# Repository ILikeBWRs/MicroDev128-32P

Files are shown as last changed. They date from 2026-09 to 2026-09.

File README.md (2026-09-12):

### *Thank You to PCBWay for sponsoring this project! To see more look up the "Sponsorship Section"*

---

Main Project Page:[MicroDev128 project](https://github.com/ILikeBWRs/MicroDev128)

---

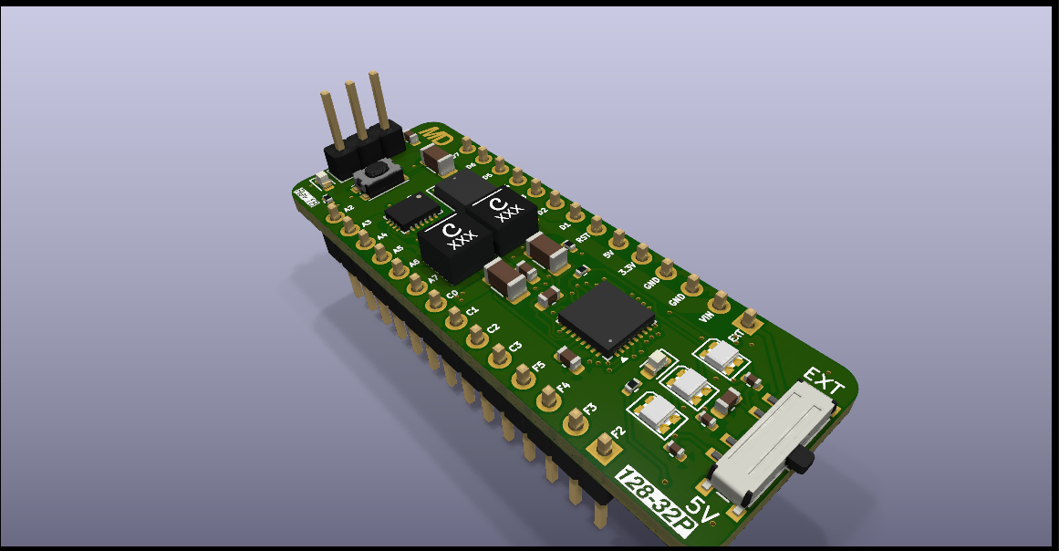
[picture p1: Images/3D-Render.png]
Project Image

# MicroDev128-32P
## A high-power development/prototyping board with MVIO. 

Based on the AVR128DB32. 

The MicroDev128-32P is open-source development board with a high-power voltage regulator with up to 2A continous, Multi-voltage IO - which allows PortC to run on a different voltage than the rest of the board - elimenating the need for voltage level shifters. The MicroDev128-32P aims to be better price to performance ratio than a tradition Arduino Nano. To view the Schematics you can go into the Kicad files folder. All files were made on KiCad 10.04 and should import without other dependencies. The 3D models are all included in the folder. 

**Key Specifications:**
- Up to 2A continuos on both power lines, 3.3v and 5v with up to 42VDC input
- Arduino Nano sized footprint, allowing it to easily be plugged into breadboards
- 128kB Flash, 16kB SRAM, and 512B EEPROM
- Has with internal clock adjustable up to 24MHz max
- Built in reverse polarity protection, fuse and overcurrent/short protection
- UPDI Header for programming 
- Onboard LED and 3 programble, seperatly adressable NeoPixels

## Documentation

For Documentation see the MicroDev128 Docs repository. This includes technical information such as regulator ripple, tests etc. 
[Link to Documents](https://github.com/ILikeBWRs/MicroDev128-Documentation)

---

## Images
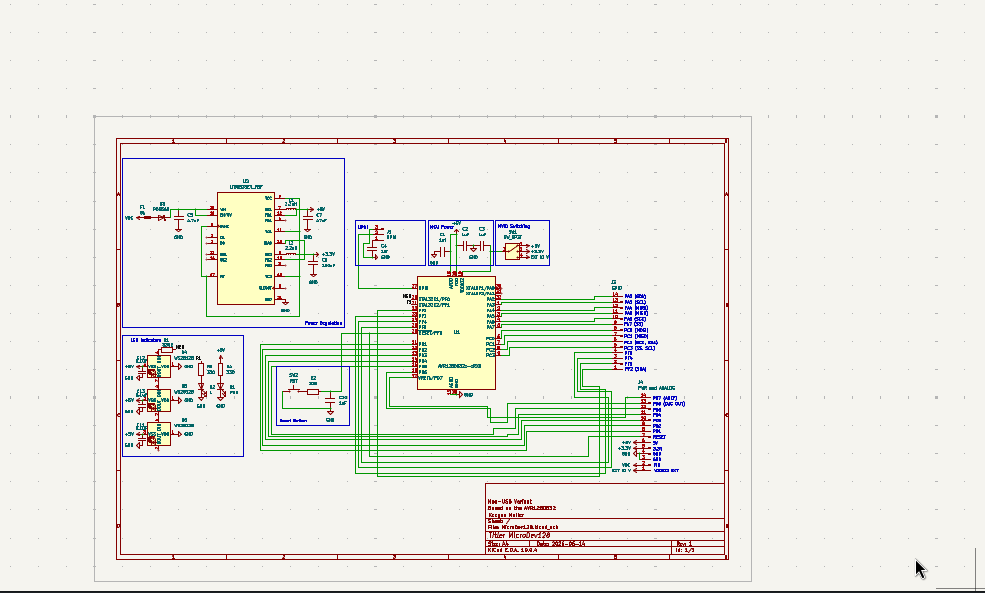
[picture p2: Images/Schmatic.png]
Schematic

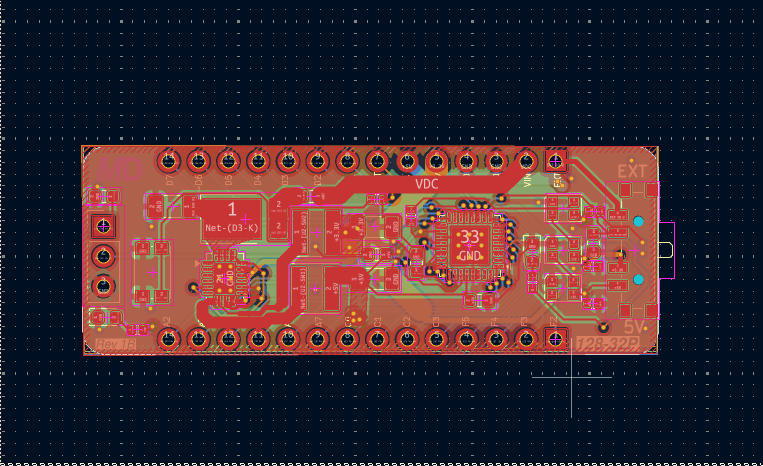
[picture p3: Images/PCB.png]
PCB Layout

3D Render

---

## Ordering

To order your own you have a few ways:

**1. Order Blank PCBs and assemble them yourself**

*You will need a hotplate for solder reflow and solder paste. May be cheaper but harder to do!*

Upload the Gebers at:
/MicroDev128-32P Production Files
   /Gebers.zip
Go to PCBWay's online ordering page and upload the gebers. Make sure it says 4-layers. Set it to ENIG, and set the solder mask to any colour you want. The rest of the default settings will be fine. Hit order or add stencil if you need one. It's that easy!

Next in the same folder find the BOM.csv and order the parts from your favorite part distributor. 
To lay out components once they turn up you can use the KiCad PCB layout. A dedicated image for this step will come later.

**2. Use PCBWay's PCBA service and get them shipped assembled**

Upload the Gebers at:

/Production Files

   /Gebers.zip
   
Go to your PCB and upload the gebers. Make sure it says 4-layers. Set it to ENIG, and set the solder mask to any colour you want. The default settings will be fine.
Then upload the BOM.csv and CPL.csv to the page. Then check if they in stock. (You may need to pre-order some parts!)
The check component orientation - it has a tendency to flip the LT8653S by 90 degrees. 
Then pay and let PCBWay's professional automated factory ship them fully assembled, right to your door!

---

## Revision Information

This repository was last updated: *2026-09-12*

This design is revision: *1B*

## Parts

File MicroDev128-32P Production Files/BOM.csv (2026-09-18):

Ref Des | Footprint | Quantity | Designation | Manufacturer | Mfg Part# | Desciption/Value | Package | Type | Notes
C1, C2, C3, C4 | C_0603_1608Metric | 4 | 1uf | Yageo | CC0603KRX5R6BB105 | 1uF 0603 X5R, ±10% | 603 | SMD | Not strict – generic options will work fine if they match the specifications.
C5 | C_1206_3216Metric | 1 | 4.7uF | Murata | GRM31CC72A475KE11K | 4.7uF 1206 ±10% X7S | 1206 | SMD
C6 | C_1206_3216Metric | 1 | 100uF | Murata | GRM31CR60J107ME39L | 100µF, 6.3V, ±20% X5R | 1206 | SMD
C7 | C_1206_3216Metric | 1 | 47uF | Murata | GRM31CR61A476ME15L | 47µF, 10V, ±20% X5R | 1206 | SMD
C10 | C_0603_1608Metric | 1 | 1uF | Yageo | CC0603KRX5R6BB105 | 1uF 0603 X5R, ±10% | 603 | SMD
C11, C12, C13 | C_0402_1005Metric | 3 | 0.1uF | Murata | GRM155R71A104KA01D | 0.1uF 402 ±10% X7R | 402 | SMD
D1 | LED_0603_1608Metric | 1 | PWR | Everlight | 19-217/R6C-AL1M2VY/3T | Standard Red SMD Led | 603 | SMD
D2 | LED_0603_1608Metric | 1 | L | Everlight | 19-217/R6C-AL1M2VY/3T | Standard Red SMD Led | 603 | SMD
D3 | D_PowerDI-5 | 1 | PDS560 | Diodes Incorporated | PDS560-13 | Schottky 60V 5A | PowerDI-5 | SMD
D4, D5, D6 | LED_WS2812B-2020_PLCC4_2.0x2.0mm | 3 | WS2812B | Worldsemi | WS2812B-2020 | RGB with IC, 5V, 2.0x2.0mm | PLCC-4 | SMD
F1 | Fuse_0603_1608Metric | 1 | 5A | Bourns | SF-0603F500-2 | 5A, 32V, Fast-Acting | 603 | SMD
J1 | PinHeader_1x03_P2.54mm_Vertical | 1 | UPDI | DNP | DNP | DNP | DNP | DNP | No Not Place
J3 | PinHeader_1x14_P2.54mm_Vertical | 1 | GPIO | DNP | DNP | DNP | DNP | DNP | No Not Place
J4 | PinHeader_1x14_P2.54mm_Vertical | 1 | PWR and ANALOG | DNP | DNP | DNP | DNP | DNP | No Not Place
L1, L2 | L_Taiyo-Yuden_NR-40xx | 2 | 2.2uH | Taiyo Yuden | NR4018T2R2M | 2.2µH, ±20%, 2.70A | 4.0x4.0mm | SMD
R1 | R_0402_1005Metric | 1 | 330R | Yageo | RC0402FR-07330RL | 330Ohm 1% 1/16W Metal film resistor | 402 | SMD
R2, R3, R4 | R_0402_1005Metric | 3 | 330R | Yageo | RC0402FR-07330RL | 330Ohm 1% 1/16W Metal film resistor | 402 | SMD
SW1 | SW_SP3T_PCM13 | 1 | SW_SP3T | C&K / Littelfuse | PCM13SMTR | Slide, SP3T, 3-Position, 0.3A 6VDC | PCM13 | SMD
SW2 | SW_Push_1P1T_NO_CK_KMR2 | 1 | RST | C&K / Littelfuse | KMR221G LFS | SPST-NO, Top Actuated, 50mA 32VDC | 4.6x2.8mm | SMD
U1 | QFN-32-1EP_5x5mm_P0.5mm_EP3.1x3.1mm | 1 | AVR128DB32x-xRXB | Microchip Technology | AVR128DB32-E/RXB | AVR Microcontroller, 128kB Flash | QFN-32 | SMD
U2 | QFN-20-1EP_3x4mm_P0.5mm_EP1.65x2.65mm | 1 | LT8653SEV_PBF | Analog Devices | LT8653SEV#PBF | Silent Switcher2 High Power Buck Reg | QFN-20 | SMD

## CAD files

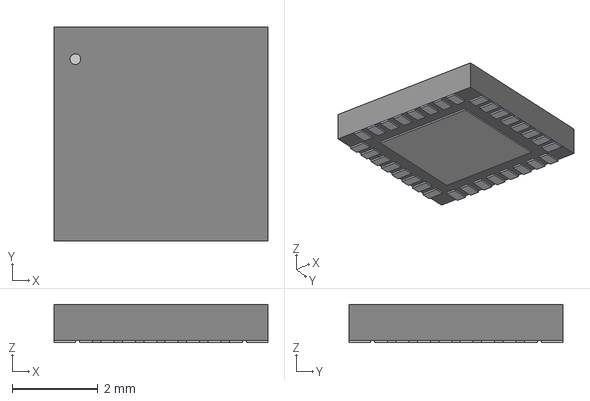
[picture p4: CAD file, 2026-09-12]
KiCad Files/3D Models/VQFN32_RXB_MCH.step
5.00 x 5.00 x 0.892 mm

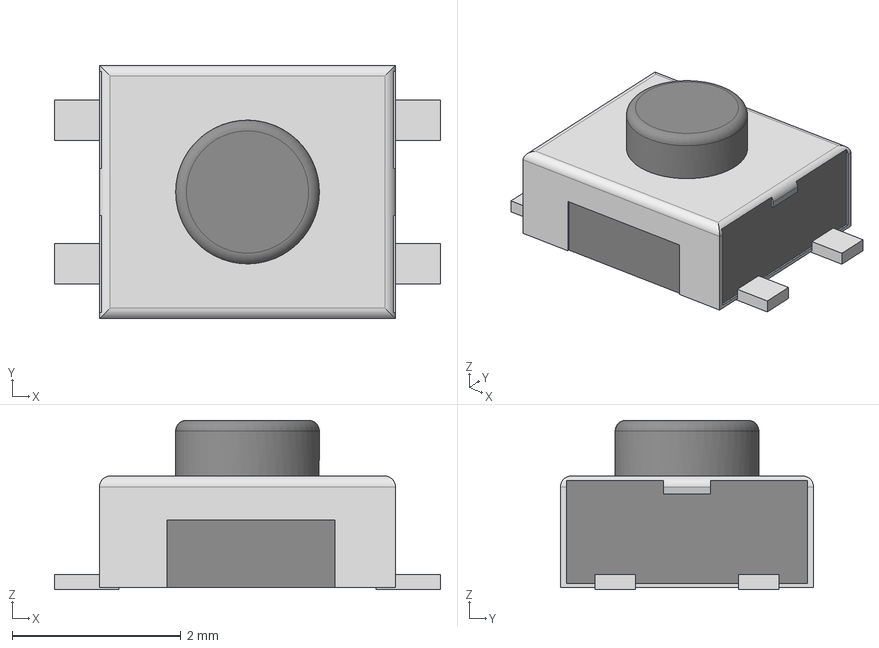
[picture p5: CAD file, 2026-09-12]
KiCad Files/3D Models/3x4x2mm.stp
4.57 x 3.00 x 2.01 mm

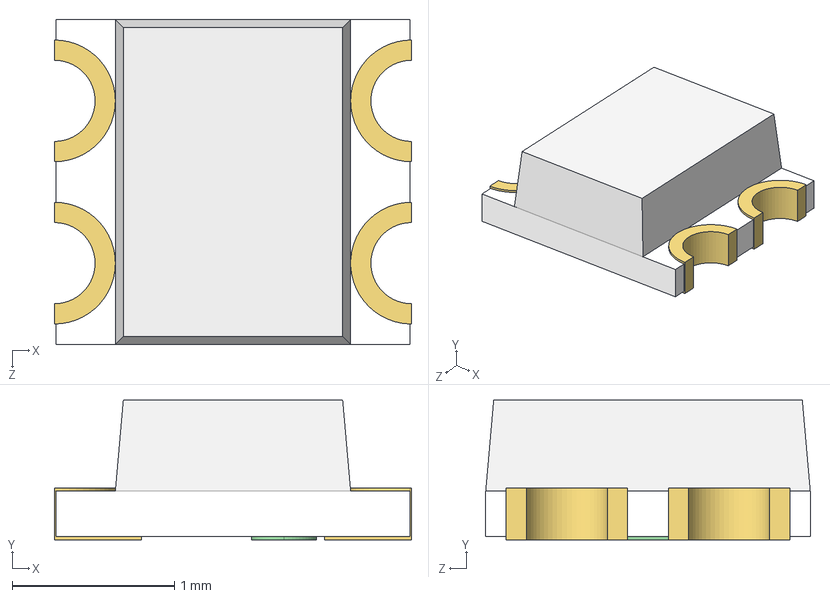
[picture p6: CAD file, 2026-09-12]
KiCad Files/3D Models/WS2812-2020.STEP
2.20 x 0.86 x 2.00 mm

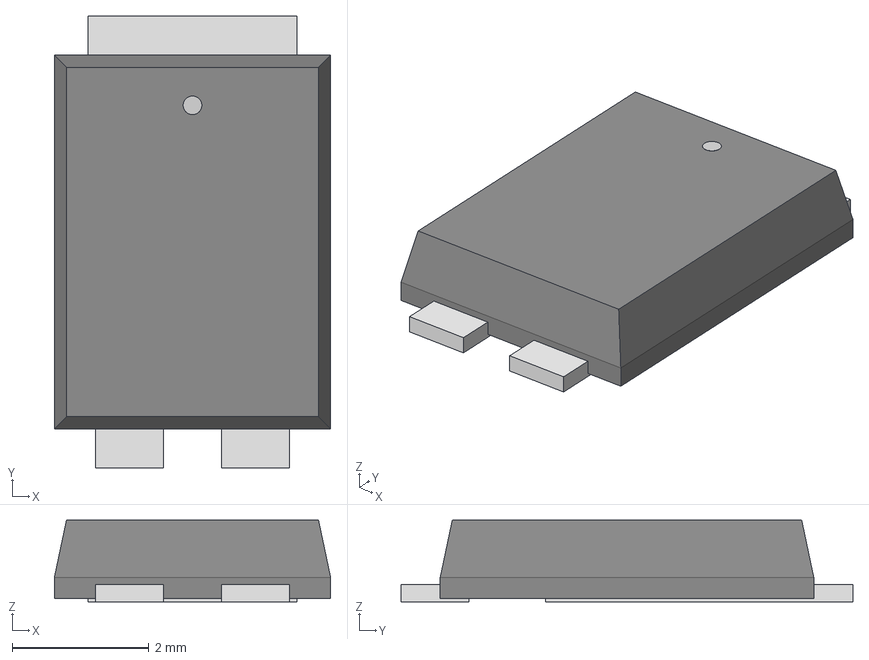
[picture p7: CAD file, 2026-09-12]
KiCad Files/3D Models/DIO_AP02001_DIO.step
4.04 x 6.60 x 1.20 mm

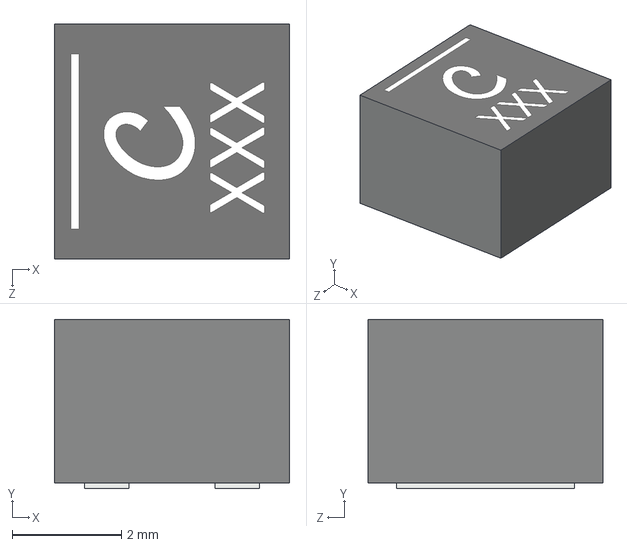
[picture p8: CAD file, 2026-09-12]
KiCad Files/3D Models/XGL4030.STEP
4.30 x 3.10 x 4.30 mm

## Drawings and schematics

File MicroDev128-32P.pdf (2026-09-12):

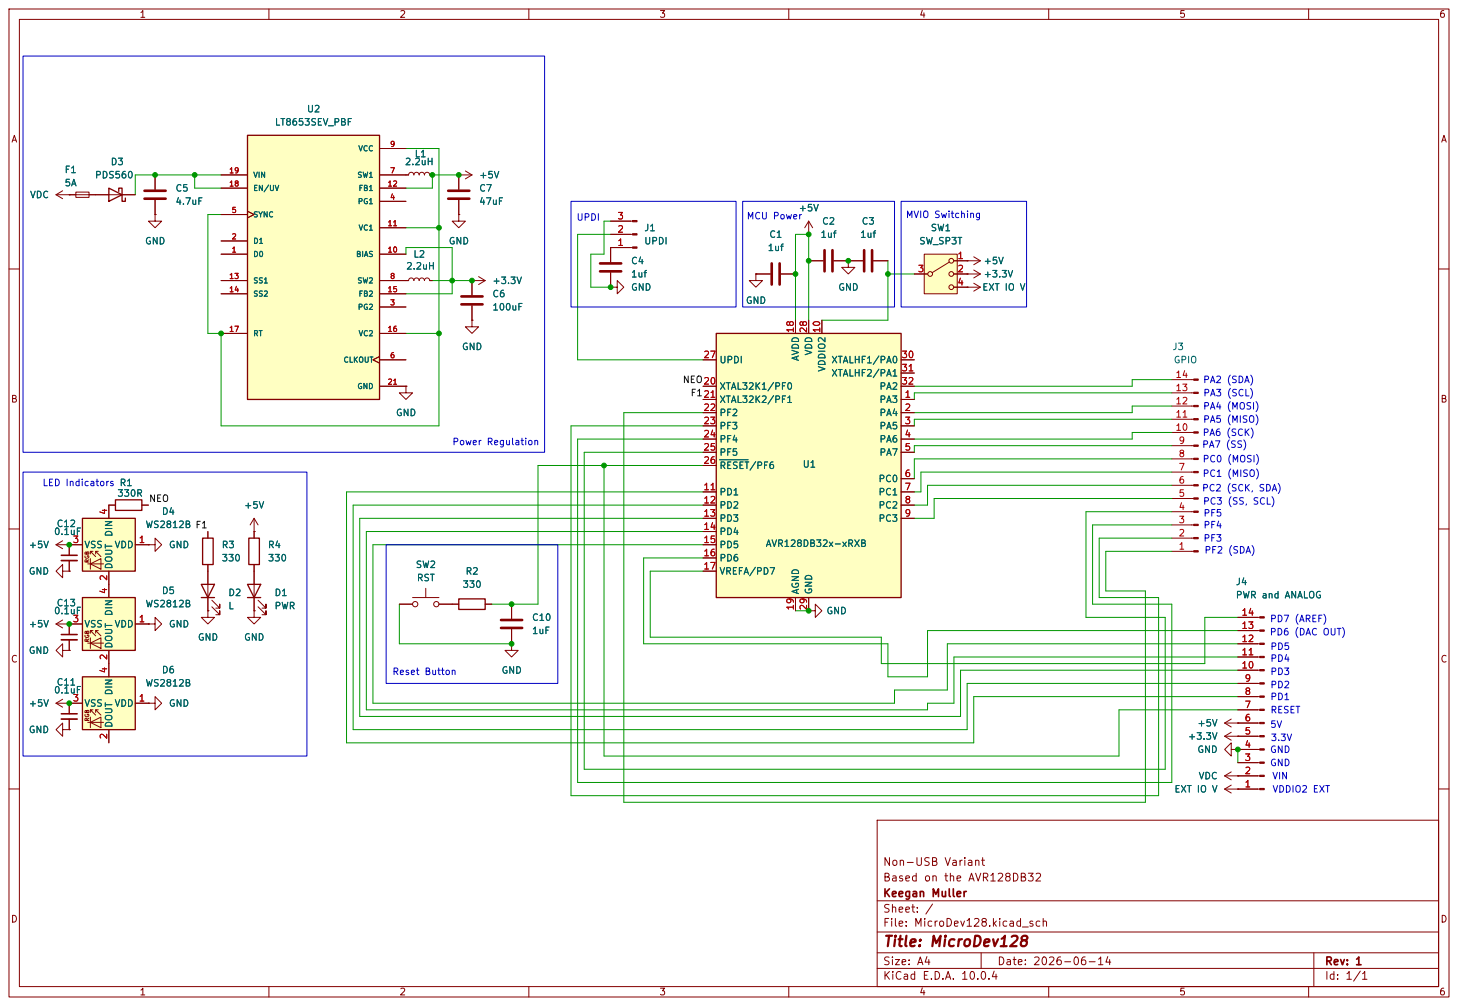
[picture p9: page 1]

Non-USB Variant GND

J4PWR and ANALOG +5V EXT IO V GND +3.3V GND

Size: A4 | Rev: 1
KiCad E.D.A. 10.0.4 | Id: 1/1

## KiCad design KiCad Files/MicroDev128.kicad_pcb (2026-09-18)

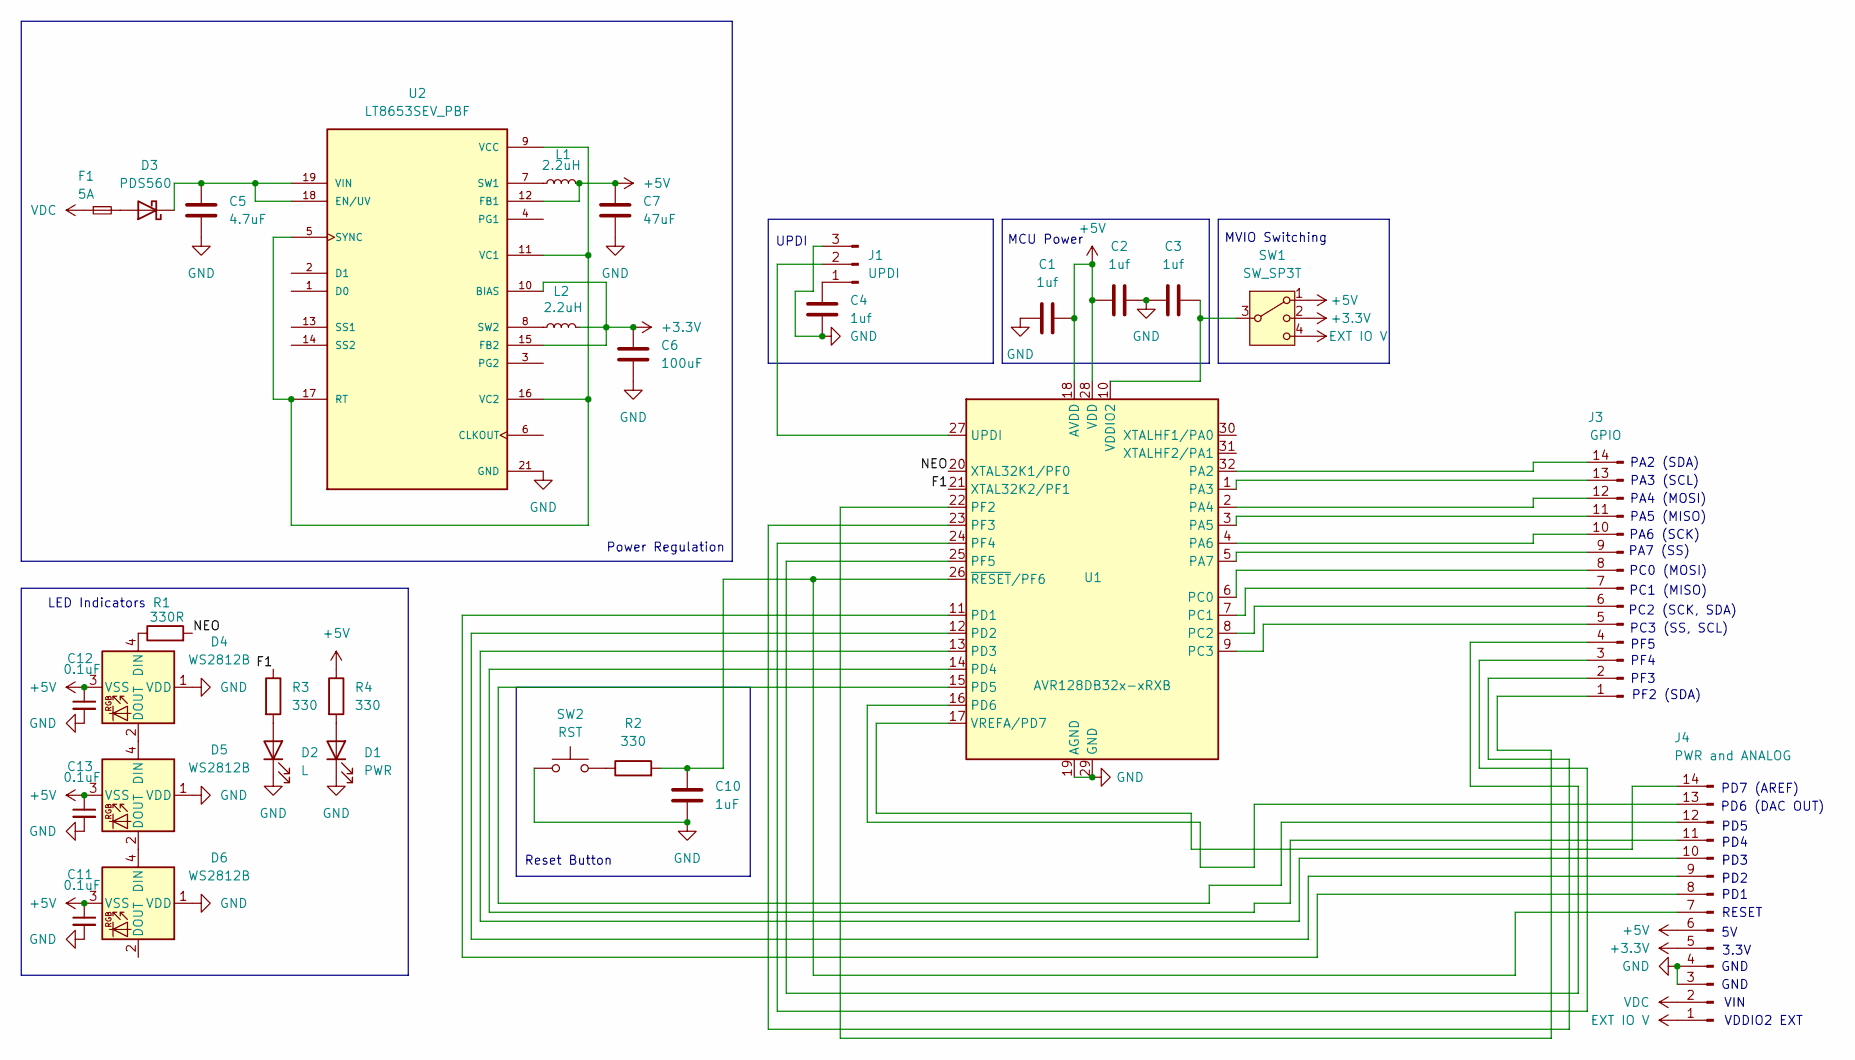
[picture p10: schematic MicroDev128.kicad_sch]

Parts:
C1, C2, C3, C4: 1uf; C_0603_1608Metric
C5: 4.7uF; C_1206_3216Metric
C6: 100uF; C_1206_3216Metric
C7: 47uF; C_1206_3216Metric
C10: 1uF; C_0603_1608Metric
C11, C12, C13: 0.1uF; C_0402_1005Metric
D1: PWR; LED_0603_1608Metric
D2: L; LED_0603_1608Metric
D3: PDS560; D_PowerDI-5
D4, D5, D6: WS2812B; LED_WS2812B-2020_PLCC4_2.0x2.0mm
F1: 5A; Fuse_0603_1608Metric
J1: UPDI; PinHeader_1x03_P2.54mm_Vertical
J3: GPIO; PinHeader_1x14_P2.54mm_Vertical
J4: PWR and ANALOG; PinHeader_1x14_P2.54mm_Vertical
L1, L2: 2.2uH; L_Taiyo-Yuden_NR-40xx
R1: 330R; R_0402_1005Metric
R2, R3, R4: 330; R_0402_1005Metric
SW1: SW_SP3T; SW_SP3T_PCM13
SW2: RST; SW_Push_1P1T_NO_CK_KMR2
U1: AVR128DB32x-xRXB; QFN-32-1EP_5x5mm_P0.5mm_EP3.1x3.1mm
U2: LT8653SEV_PBF; QFN-20-1EP_3x4mm_P0.5mm_EP1.65x2.65mm; PARTREV B

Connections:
+3.3V: C6.1, J4.5, L2.2, SW1.2, U2.10 (BIAS), U2.15 (FB2)
+5V: C1.2, C2.1, C7.1, C11.1, C12.1, C13.1, D4.3 (VSS), D5.3 (VSS), D6.3 (VSS), J4.6, L1.2, R4.1, SW1.1, U1.18 (AVDD), U1.28 (VDD), U2.12 (FB1)
/F1: R3.1, U1.21 (XTAL32K2/PF1)
/NEO: R1.2, U1.20 (XTAL32K1/PF0)
EXT IO V: J4.1, SW1.4
GND: C1.1, C2.2, C3.1, C4.2, C5.2, C6.2, C7.2, C10.2, C11.2, C12.2, C13.2, D1.1 (K), D2.1 (K), D4.1 (VDD), D5.1 (VDD), D6.1 (VDD), J1.3, J4.3, J4.4, SW2.1, U1.19 (AGND), U1.29 (GND), U1.33 (GND), U2.21 (GND)
unnamed: D1.2 (A), R4.2
unnamed: D2.2 (A), R3.2
unnamed: D3.2 (A), F1.2
unnamed: C5.1, D3.1 (K), U2.18 (EN/UV), U2.19 (VIN), U2.20 (VIN)
unnamed: D4.4 (DIN), R1.1
unnamed: D4.2 (DOUT), D5.4 (DIN)
unnamed: D5.2 (DOUT), D6.4 (DIN)
unnamed: C4.1, J1.1
unnamed: J1.2, U1.27 (UPDI)
unnamed: J3.1, U1.22 (PF2)
unnamed: J3.2, U1.23 (PF3)
unnamed: J3.3, U1.24 (PF4)
unnamed: J3.4, U1.25 (PF5)
unnamed: J3.5, U1.9 (PC3)
unnamed: J3.6, U1.8 (PC2)
unnamed: J3.7, U1.7 (PC1)
unnamed: J3.8, U1.6 (PC0)
unnamed: J3.9, U1.5 (PA7)
unnamed: J3.10, U1.4 (PA6)
unnamed: J3.11, U1.3 (PA5)
unnamed: J3.12, U1.2 (PA4)
unnamed: J3.13, U1.1 (PA3)
unnamed: J3.14, U1.32 (PA2)
unnamed: C10.1, J4.7, R2.2, U1.26 (~RESET/PF6)
unnamed: J4.8, U1.11 (PD1)
unnamed: J4.9, U1.12 (PD2)
unnamed: J4.10, U1.13 (PD3)
unnamed: J4.11, U1.14 (PD4)
unnamed: J4.12, U1.15 (PD5)
unnamed: J4.13, U1.16 (PD6)
unnamed: J4.14, U1.17 (VREFA/PD7)
unnamed: R2.1, SW2.2
unnamed: C3.2, SW1.3, U1.10 (VDDIO2)
unnamed: U2.5 (SYNC), U2.9 (VCC), U2.11 (VC1), U2.16 (VC2), U2.17 (RT)
unnamed: L1.1, U2.7 (SW1)
unnamed: L2.1, U2.8 (SW2)
VDC: F1.1, J4.2

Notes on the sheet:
PD5
PC2 (SCK, SDA)
LED Indicators
GND
PA5 (MISO)
3.3V
UPDI
PD3
Reset Button
PF4
PA7 (SS)
PC0 (MOSI)
PD2
VIN
PF2 (SDA)
PF3
PA4 (MOSI)
RESET
PD6 (DAC OUT)
PF5
PA2 (SDA)
Power Regulation
PA6 (SCK)
PC1 (MISO)
MVIO Switching
VDDIO2 EXT
PD7 (AREF)
PA3 (SCL)
PD1
PC3 (SS, SCL)
PD4
MCU Power
GND

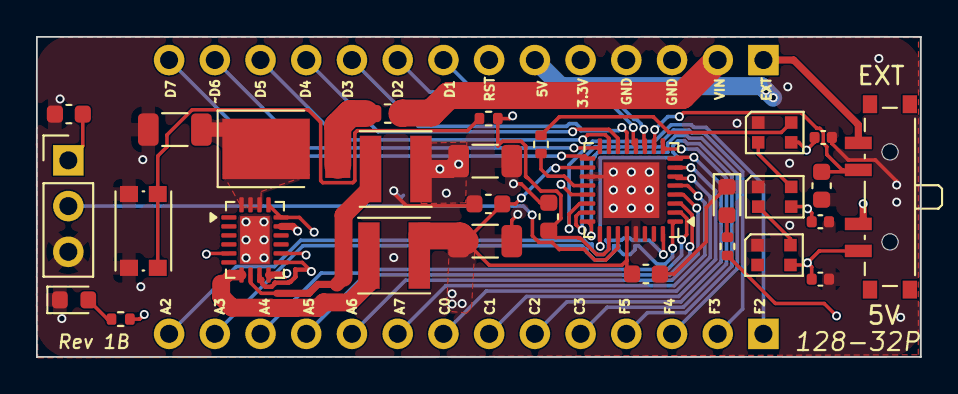
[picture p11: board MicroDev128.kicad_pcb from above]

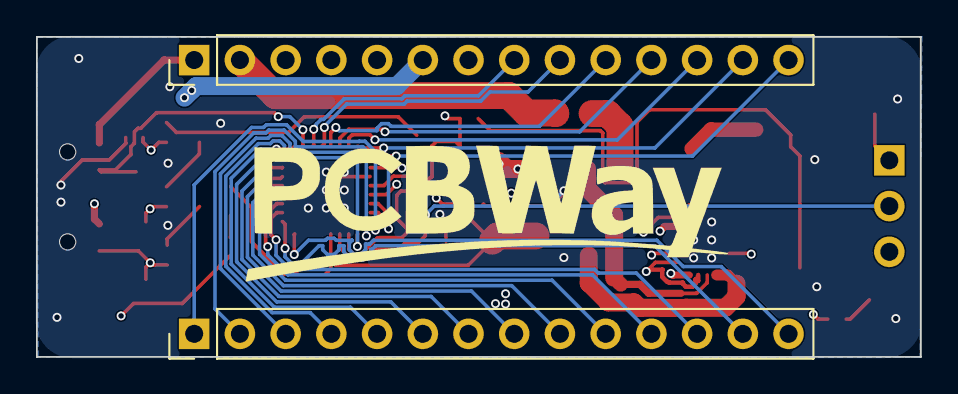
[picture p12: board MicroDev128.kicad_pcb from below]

Board: 4 copper layers, 49.1 x 17.8 mm, 31 parts (2 on the bottom side), 43 nets.
